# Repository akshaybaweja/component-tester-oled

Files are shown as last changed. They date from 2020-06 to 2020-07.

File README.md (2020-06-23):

# Component Tester OLED (Keychain) 

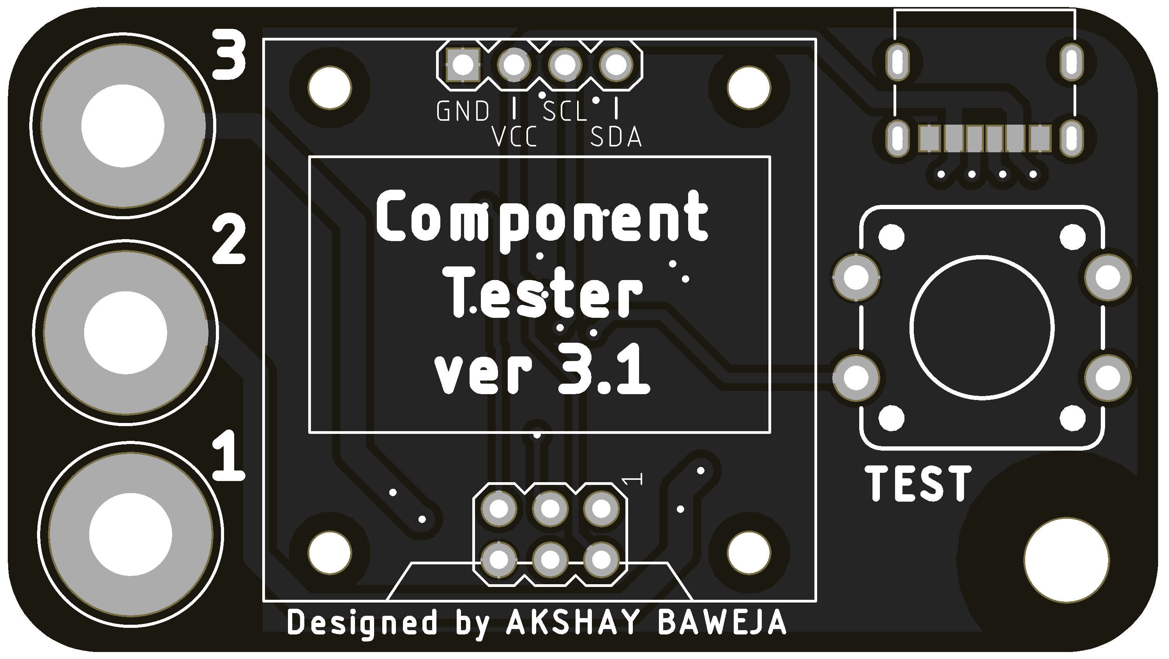
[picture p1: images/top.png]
TOP PCB

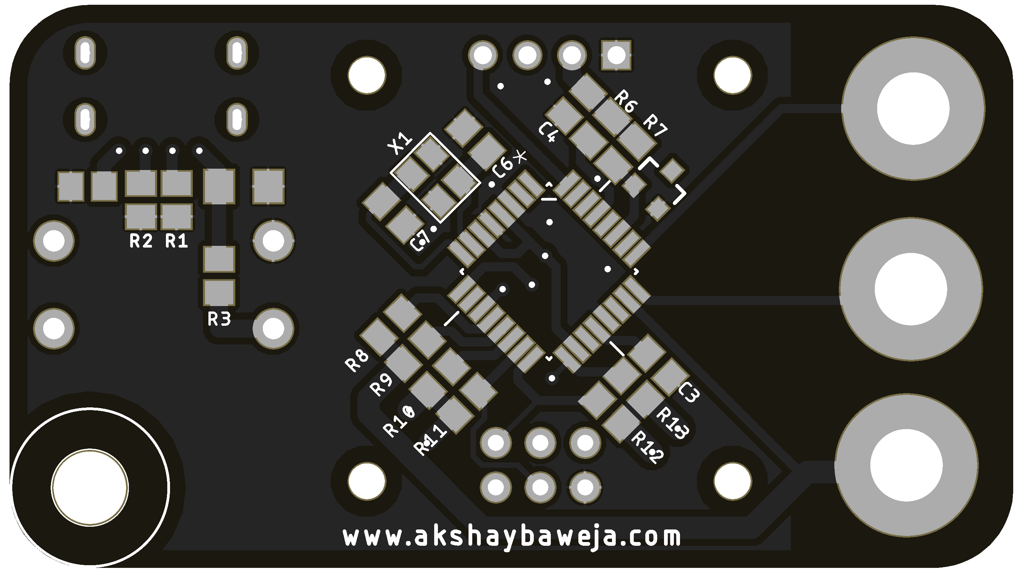
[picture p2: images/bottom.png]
BOTTOM PCB


## Sending PCBs for fabrication

1. Download the [Gerber Files](GERBER_FILES.zip)
2. Goto [PCBWAY](https://www.pcbway.com/QuickOrderOnline.aspx) for sending files for fabrication
3. Upload **GERBER_FILES.zip** using the **+Add Gerber File** option
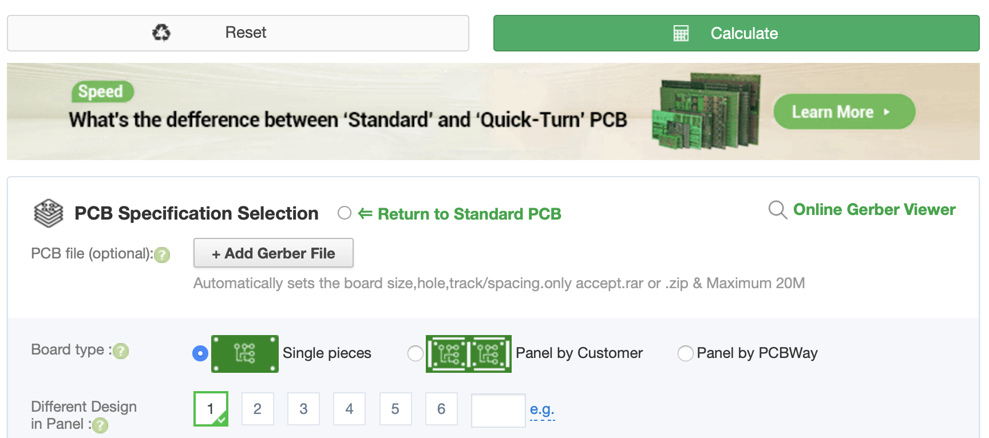
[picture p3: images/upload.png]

4. Select Quantity of PCBs
5. Select your desired *soldermask color*.
6. Select your shipping method on thr right
7. Click **Save to Cart** and **Checkout**

## Bill of Materials
|Qty|Designator|Package|Value|Description|MANUFACTURER PART NUMBER|
|---|---|---|-----|---|---|
|1|C2|0805|100nF|CAP CER 0805 0.1UF 100V X7R|C0805C104K1RECAUTO|
|1|C3|0805|1nF|CAP CER 1000PF 50V C0G/NP0 0805|C0805C102J5GACTU|
|1|C4|0805|10nF|CAP CER 0805 10NF 100V X7R|C0805X103K1RAC3316|
|1|C5|1206|10uF|CAP CER 10UF 25V X5R 1206|C1206C106M3PACTU|
|2|C6, C7|0805|22pF|CAP CER 22PF 50V C0G/NP0 0805|C0805C220J5GACTU|
|2|R1, R2|0805|5.1kΩ|RES 5.1K OHM 5% 1/4W 0805|RK73B2ATTD512J|
|1|R3|0805|27kΩ|RES SMD 27K OHM 1% 1/8W 0805|CRG0805F27K|
|1|R6|0805|10kΩ|RES 10K OHM 1% 1/4W 0805|RNCP0805FTD10K0|
|1|R7|0805|3.3kΩ|RES 3K3 OHM 1% 0805|CRGCQ0805F3K3|
|3|R8, R10, R12|0805|680Ω|RES SMD 680 OHM **0.1%** 1/4W 0805|ERJ-PB6B6800V|
|3|R9, R11, R12|0805|470kΩ|RES SMD 470K OHM **0.1%** 1/4W 0805|ERJ-PB6B4703V
|1|U1|TQFP32|ATMEGA328P-AU|IC MCU 8BIT 32KB FLASH 32TQFP|ATMEGA328P-AUR
|1|U2|SOT23-3|LM4040|IC VREF SHUNT 2% SOT23-3|LM4040EIM3X-2.5/NOPB
|1|X1|TSX-3225|16MHz|CRYSTAL 16.00 MHZ 9PF SMD|TSX-3225 16.0000MF09Z-AC0|
|1|J1|CUI_UJC-HP-3-SMT-TR|USB C (Power Only)|USB JACK, C TYPE, POWER ONLY, 6|UJC-HP-3-SMT-TR
|1|TEST|12MM PTH TACTILE SWITCH|-|SWITCH TACTILE SPST-NO 0.05A 12V|PTS125SM43-2 LFS|
|1|DISPLAY|-|-|OLED 0.96" 4 PIN I2C Interface|[Amazon](https://www.amazon.com/dp/B06XRBYJR8)|
|3|1, 2, 3|2MM BANANA JACK FEMALE|-|-|[Amazon](https://www.amazon.com/Tegg-Banana-Binding-Terminal-Connector/dp/B07GSLPCBV/)|

## Uploading Firmware

### Hardware Setup 

Using a USBasp programmer connect it to the ICSP Header on the board. Refer the following pinout for connections -

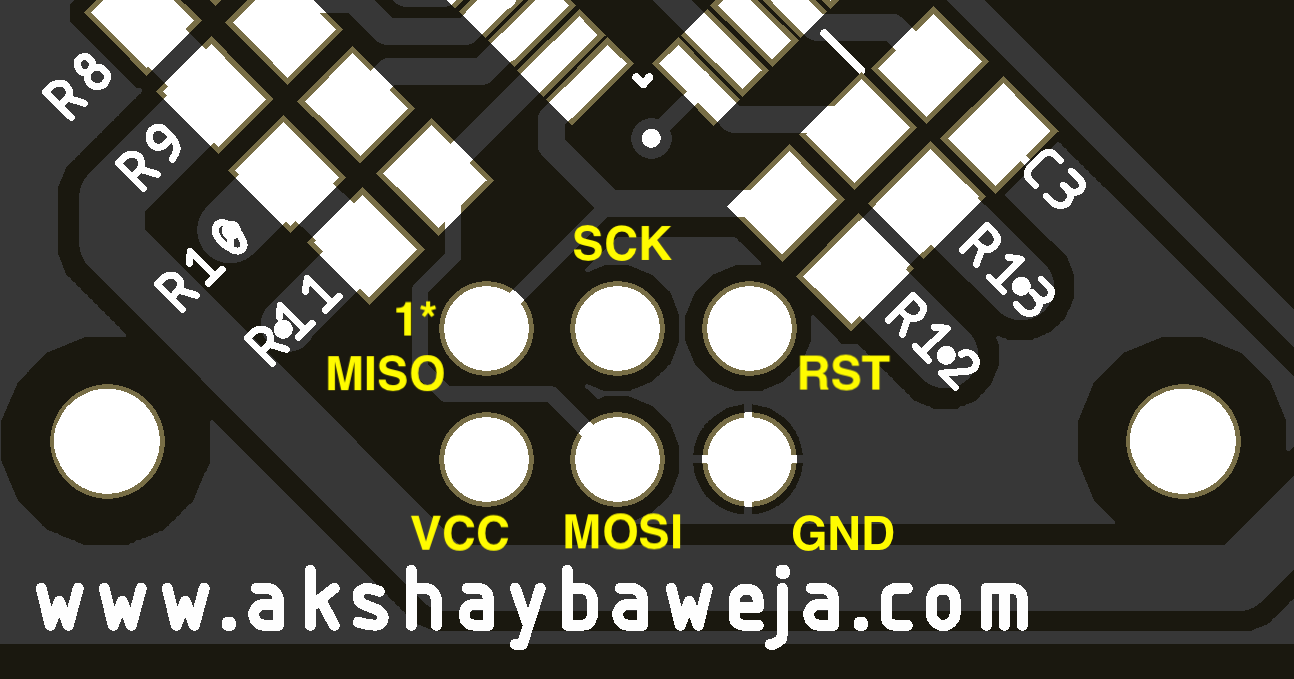
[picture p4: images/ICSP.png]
ICSP

> PCB Bottom Side

### Software Installation

>**NOTE:** AVRDUDE must be installed in your computer in order for the following instructions to work.

Open Terminal/ Command Prompt in your system, navigate to folder's location with above files and run the following commands -

#### Uploading the .HEX file and .EEP file to MCU

```
avrdude -c usbasp -B 20  -p m328p -P usb -U flash:w:./TransistorTester.hex:a -U eeprom:w:./TransistorTester.eep:a
```

#### Setting the FUSES

```
avrdude -c usbasp -B 200  -p m328p -P usb  -U lfuse:w:0xe2:m -U hfuse:w:0xd9:m -U efuse:w:0xfc:m
```

---

### References
- [Schematic](./Schematic.pdf)
- [Original Transistor Tester](https://www.mikrocontroller.net/articles/AVR_Transistortester)

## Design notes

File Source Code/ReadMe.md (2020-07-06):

# Component Tester OLED 
> For ATMega328 based tester and SSD1306 OLED Driver (128x64px)

#### Forked from [TransistorTester by Markus F.](https://github.com/svn2github/transistortester)
---
## Instructions to compile code
1. GoTo mega328_I2C_OLED and start terminal in folder
2. Make required changes to MakeFile (if no desired changes then move to next step)
3. Type the commands in following order
```
make clean
```
```
make all
```
4. Now connect your component tester to PC via USBasp Programmer
```
make fuses
```

```
make upload
```
5. Enjoy using your component tester 🥳

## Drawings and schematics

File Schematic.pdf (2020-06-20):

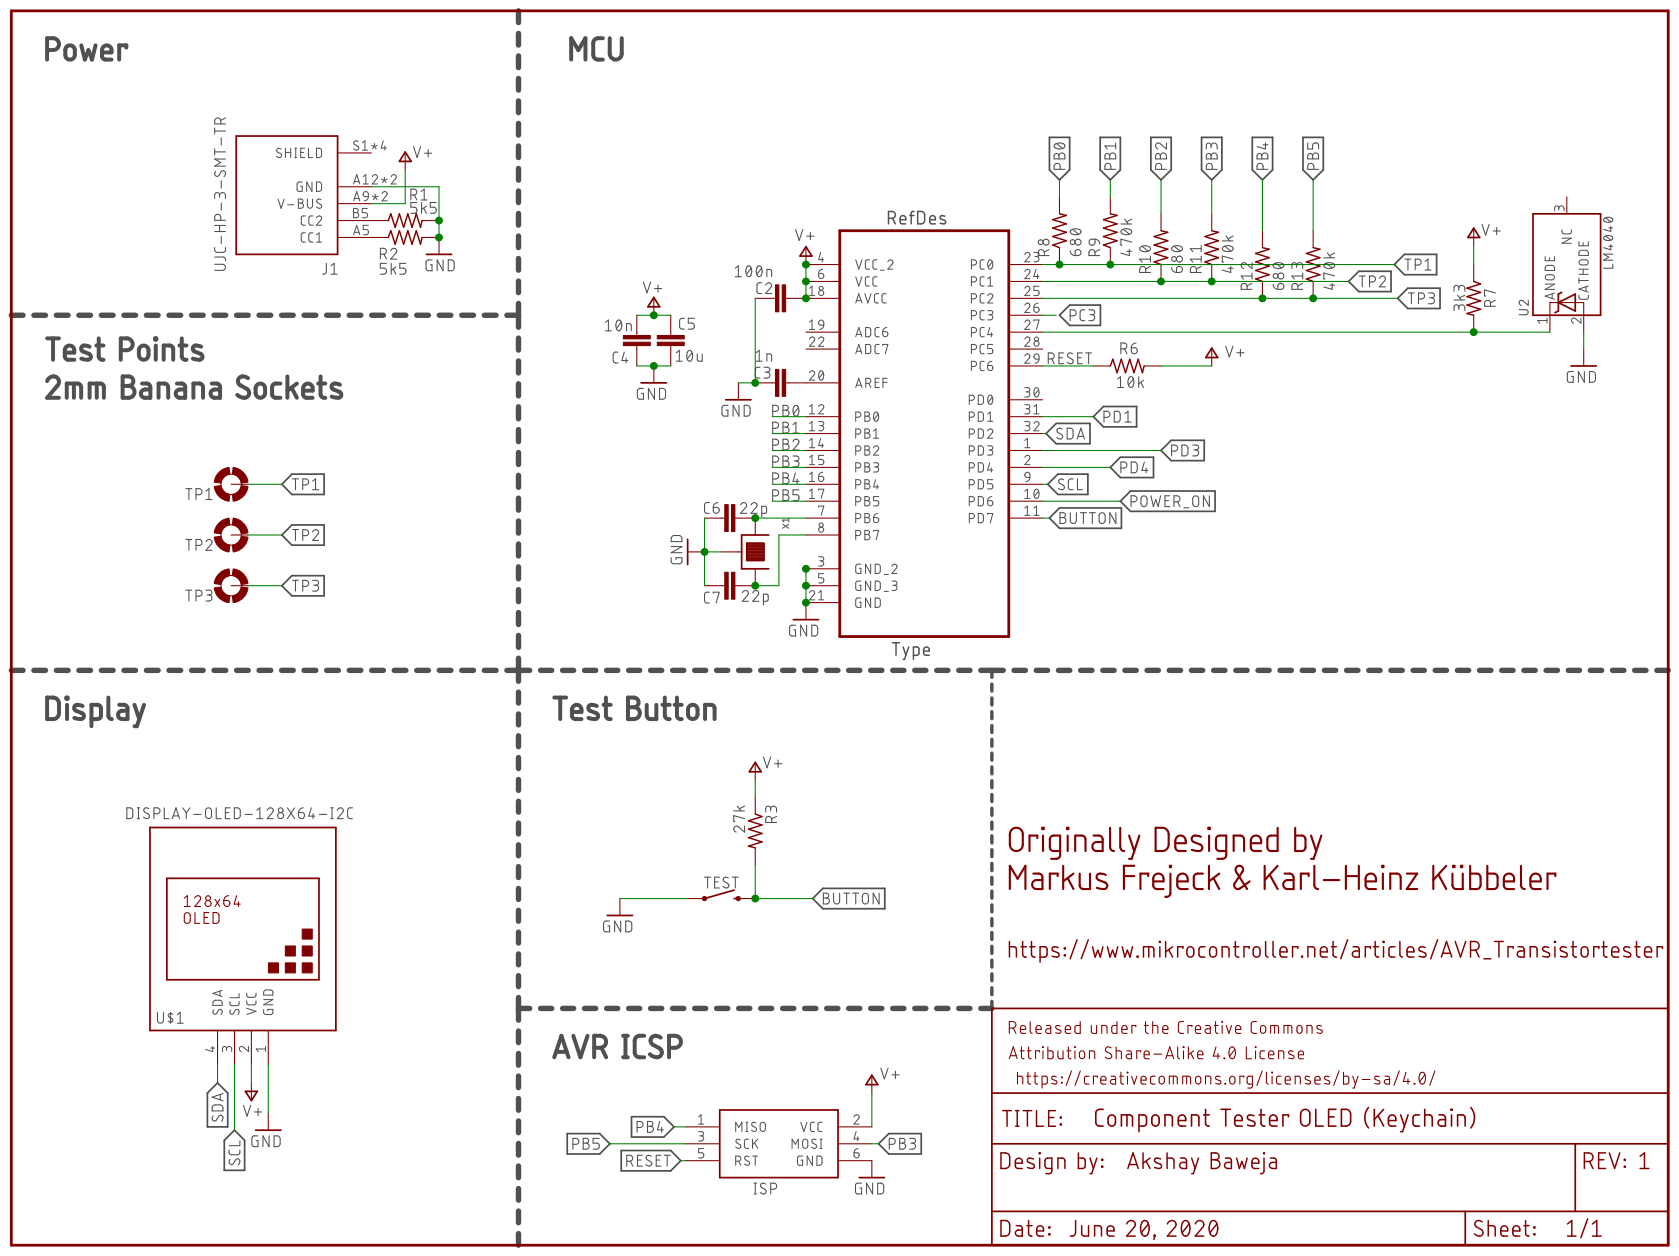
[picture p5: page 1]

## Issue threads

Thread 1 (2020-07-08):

U2 PIN NAME ISSUE

sunzhongmeng, 2020-07-08:
hello,I found the U2(LM4040) pin 1 named ANODE but the datasheet is assigned CATHODE.

akshaybaweja, 2020-07-08:
Please refer to images below the U2 is the same as LM4040's datasheet. I have links to the datasheet and schematic below. Please cross verify.

[Link to Schematic](https://github.com/akshaybaweja/component-tester-oled/blob/master/Schematic.pdf)| [Link to Datasheet // Texas Instrument](https://www.ti.com/lit/ds/symlink/lm4040-n.pdf)
:-------------------------:|:-------------------------:
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 |  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

sunzhongmeng, 2020-07-09:
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

I mean the symbol of U2,the Pin 1 should named "CATHODE",and the Pin 2 name is "ANODE" as the datasheet .

Closed 2020-07-08.

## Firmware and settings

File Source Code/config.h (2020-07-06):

/*########################################################################################
        Configuration
*/
#ifndef ADC_PORT
#if ((LCD_ST_TYPE == 7565) || (LCD_ST_TYPE == 1306) || (LCD_ST_TYPE == 7108) || (LCD_ST_TYPE == 8812) || (LCD_ST_TYPE == 8814) || (LCD_ST_TYPE == 7735) || (LCD_ST_TYPE == 9163) || (LCD_ST_TYPE == 9341) || (LCD_ST_TYPE == 1327))
  #define LCD_GRAPHIC_TYPE 1
#elif (LCD_ST_TYPE == 7920)
  #define LCD_GRAPHIC_TYPE 2
#else
  #define LCD_GRAPHIC_TYPE 0
#endif
#include "part_defs.h"
#include "lcd_defines.h"
//#define DebugOut 3		// if set, output of voltages of resistor measurements in row 2,3,4
//#define DebugOut 4		// if set, output of voltages of Diode measurement in row 3+4
//#define DebugOut 5		// if set, output of Transistor checks in row 2+3
//#define DebugOut 10		// if set, output of capacity measurements (ReadCapacity) in row 3+4 
//#define DebugOut 11		// if set, output of load time (ReadCapacity) in row 3 for C at pins 1+3

// defines for LCD_INTERFACE_MODE
#define MODE_PARALLEL 1		/* default 4-Bit parallel mode for character LCD */
				/* EN + RS + B4 + B5 + B6 + B7 */
#define MODE_I2C 2		/* I2C interface for SSD1306 */
				/* SCL + SDA */
#define MODE_3LINE 3		/* special 3 line serial output with Data/Command as first data bit  PCF8814 */
				/* RES + EN + B0 (+ CE) */
#define MODE_SPI 4		/* 4 bit SPI interface for ST7565 or SSD1306 */
				/* RES + EN + RS + B0 (+ CE) */
#define MODE_7920_SERIAL 5		/* serial interface for ST7920 */
				/* EN + B0 (+ RESET) */
#define MODE_7108_SERIAL 6		/* serial interface for ST7108 with shift register 74HC164 */
				/* EN + [RS B0] + CS1 + CS2 + CLK (+ PCLK) */
#define MODE_1803_SERIAL 7		/* serial interface for SSD1803 */
				/* EN + B0 (+ RESET) */

// select the right Processor Typ
#if defined(__AVR_ATmega48__)
 #define PROCESSOR_TYP 168
#elif defined(__AVR_ATmega48P__)
 #define PROCESSOR_TYP 168
#elif defined(__AVR_ATmega88__)
 #define PROCESSOR_TYP 168
#elif defined(__AVR_ATmega88P__)
 #define PROCESSOR_TYP 168
#elif defined(__AVR_ATmega168__)
 #define PROCESSOR_TYP 168
#elif defined(__AVR_ATmega168P__)
 #define PROCESSOR_TYP 168
#elif defined(__AVR_ATmega328__)
 #define PROCESSOR_TYP 328
#elif defined(__AVR_ATmega328P__)
 #define PROCESSOR_TYP 328
#elif defined(__AVR_ATmega324__)
 #define PROCESSOR_TYP 644
#elif defined(__AVR_ATmega324P__)
 #define PROCESSOR_TYP 644
#elif defined(__AVR_ATmega324PA__)
 #define PROCESSOR_TYP 644
#elif defined(__AVR_ATmega644__)
 #define PROCESSOR_TYP 644
#elif defined(__AVR_ATmega644P__)
 #define PROCESSOR_TYP 644
#elif defined(__AVR_ATmega644PA__)
 #define PROCESSOR_TYP 644
#elif defined(__AVR_ATmega1284__)
 #define PROCESSOR_TYP 644
#elif defined(__AVR_ATmega1284P__)
 #define PROCESSOR_TYP 644
#elif defined(__AVR_ATmega640__)
 #define PROCESSOR_TYP 1280
#elif defined(__AVR_ATmega1280__)
 #define PROCESSOR_TYP 1280
#elif defined(__AVR_ATmega2560__)
 #define PROCESSOR_TYP 1280
#else
 #define PROCESSOR_TYP 8
#endif
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
